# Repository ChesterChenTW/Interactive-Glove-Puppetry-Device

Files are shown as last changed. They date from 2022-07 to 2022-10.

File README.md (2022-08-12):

Wallpaper_Text

<p align="center">
    本專案將台灣布袋戲，結合互動裝置與開放資源
</p>
<p align="center">
    希望讓更多人能夠認識，並親自體驗傳統文化！ 
</p>  

## 開始著手
1. 下載[資源庫壓縮檔](https://github.com/ChesterChenTW/Interactive-Glove-Puppetry-Device/archive/refs/heads/main.zip)
1. 3D列印 "STL File" 資料夾內的檔案
1. 準備需要的材料，可見[物料清單](https://docs.google.com/spreadsheets/d/1u8G3vyJboXI-Y3cjxOG-QFLHkgTOIldBRjKiVYlQXxE/edit?usp=sharing)
1. 跟著[組裝指示](https://github.com/ChesterChenTW/Interactive-Glove-Puppetry-Device/wiki#%E7%B5%84%E8%A3%9D%E6%8C%87%E7%A4%BA)逐步完成裝置
1. 體驗以手把操控戲偶的樂趣！

## 授權條款
<br />本資源平台提供的內容均採用<a rel="license" href="https://creativecommons.org/licenses/by/4.0/deed.zh_TW">創用 CC 姓名標示 4.0 國際 授權條款</a>授權。  
允許重製、散布、傳輸以及修改著作（包括商業性利用），惟使用時須註明本平台的連結。

⚠️ 注意
1. 本平台僅作為內容提供，不對任何衍生或使用之損害負責，使用者須自行評估並注意安全
1. 修改原始檔案（例如韌體）可能影響裝置控制機制，建議需具備一定工程能力

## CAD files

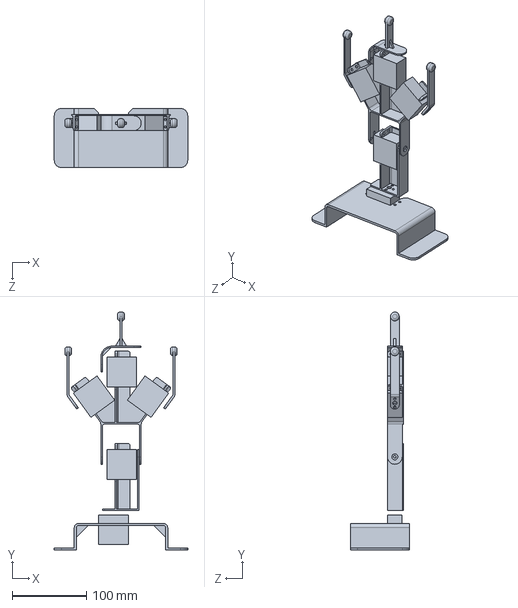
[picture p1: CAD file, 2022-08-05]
Original CAD File/Solidworks 2018/robotic.SLDPRT
180.0 x 320.7 x 80.0 mm

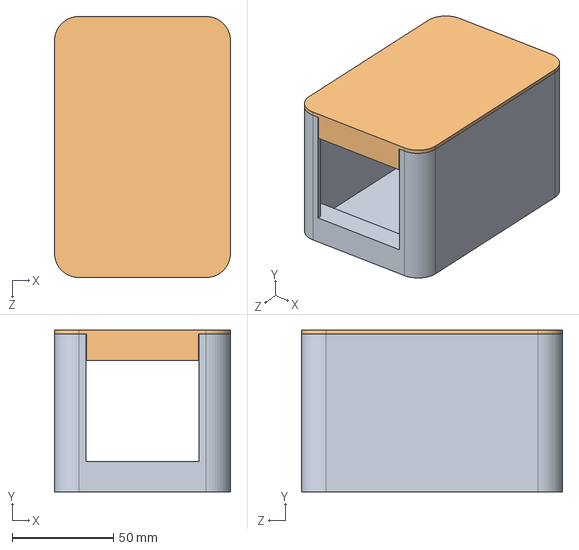
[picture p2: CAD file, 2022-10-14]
Original CAD File/STEP/robotic case.STEP
87.0 x 80.0 x 129.0 mm

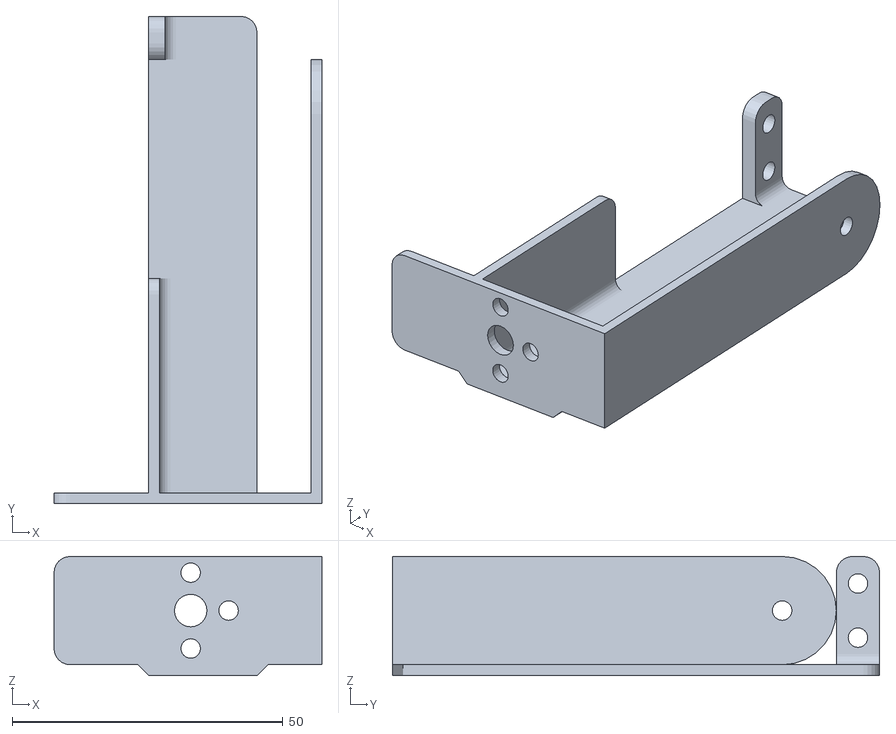
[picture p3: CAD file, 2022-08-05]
STL File/robotic_lower body.STL
49.5 x 90.0 x 22.0

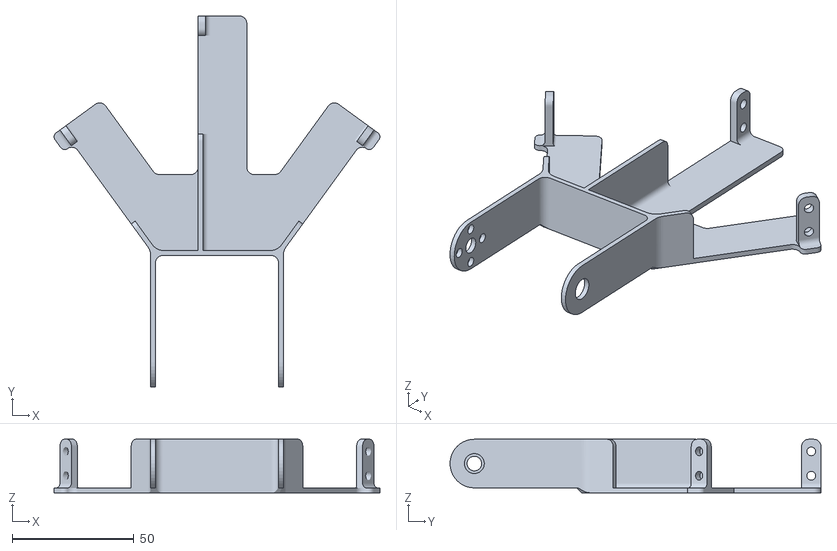
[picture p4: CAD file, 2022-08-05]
STL File/robotic_upper body.STL
133.9 x 152.4 x 22.0

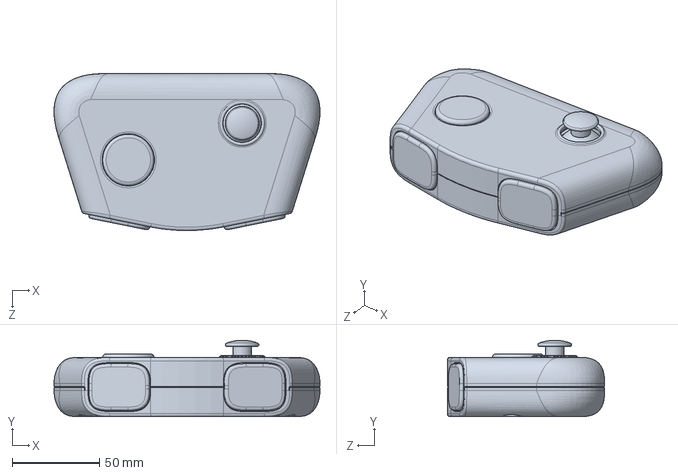
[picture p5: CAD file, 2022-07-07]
Original CAD File/Solidworks 2018/controller.SLDPRT
152.3 x 43.8 x 89.9 mm

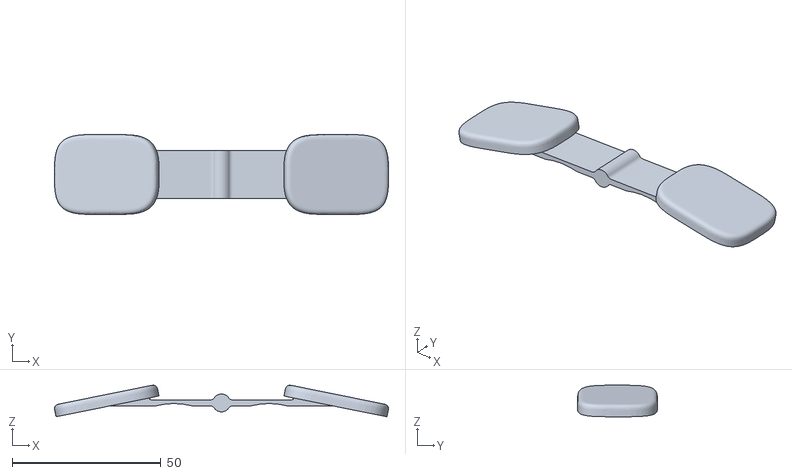
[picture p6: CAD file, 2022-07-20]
STL File/controller_shoulder button.STL
112.3 x 26.8 x 10.6

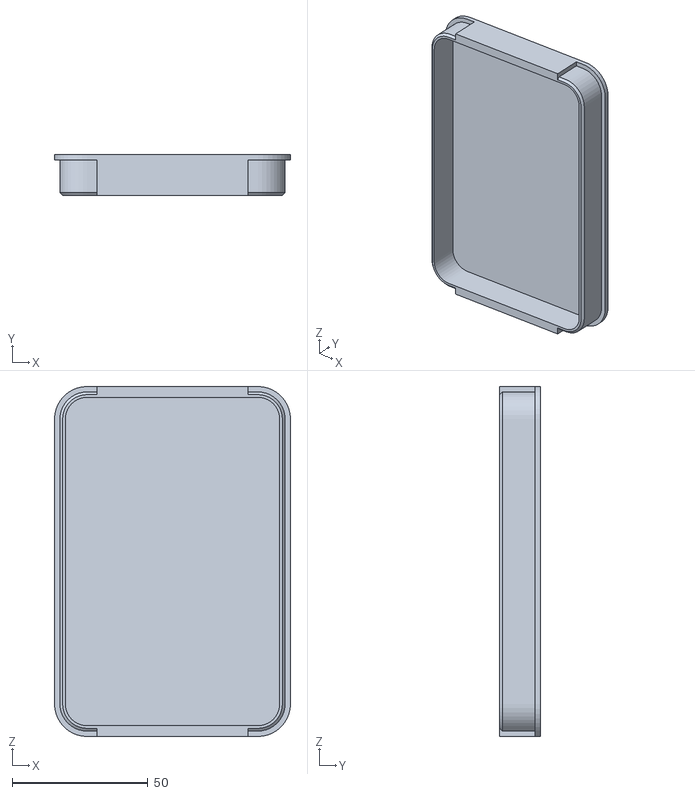
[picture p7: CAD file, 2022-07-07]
STL File/robotic case_cover.STL
87.0 x 15.0 x 129.0

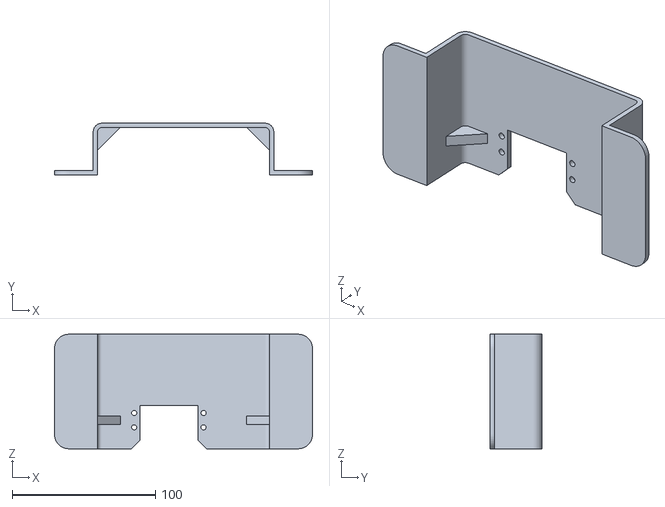
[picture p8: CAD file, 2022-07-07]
STL File/robotic_bottom.STL
180.0 x 36.0 x 80.0

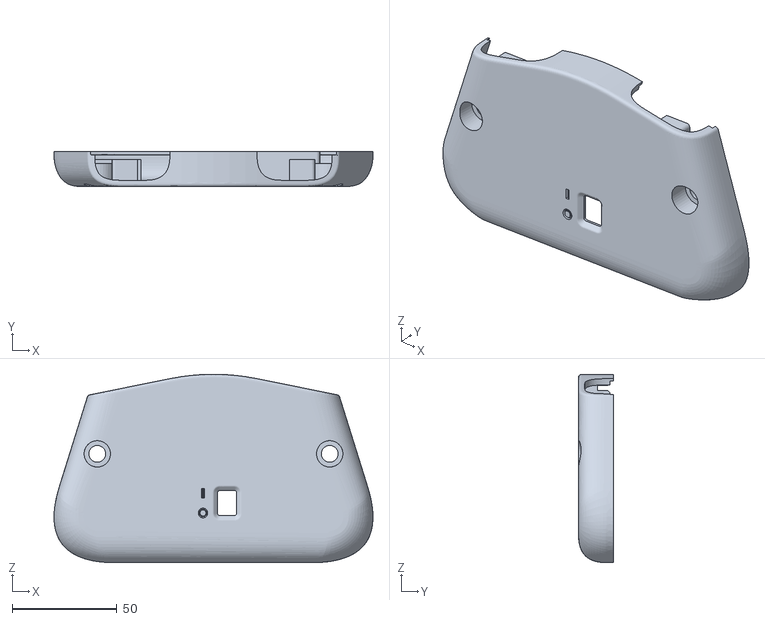
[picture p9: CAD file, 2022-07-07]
STL File/controller_bottom cover.STL
152.3 x 16.8 x 90.0

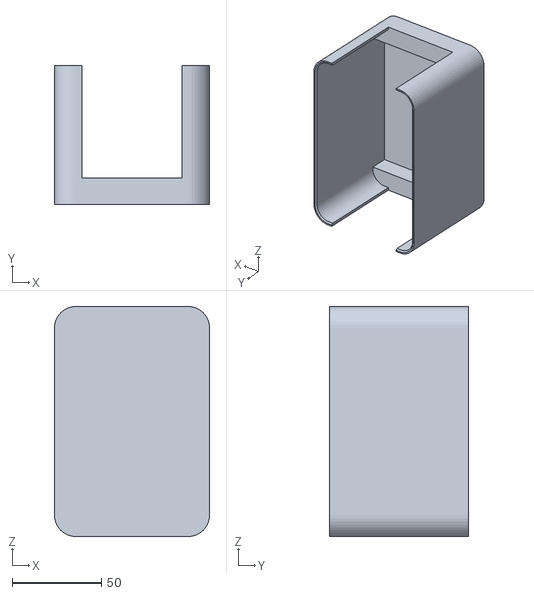
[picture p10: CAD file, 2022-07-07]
STL File/robotic case_case.STL
87.0 x 78.0 x 129.0

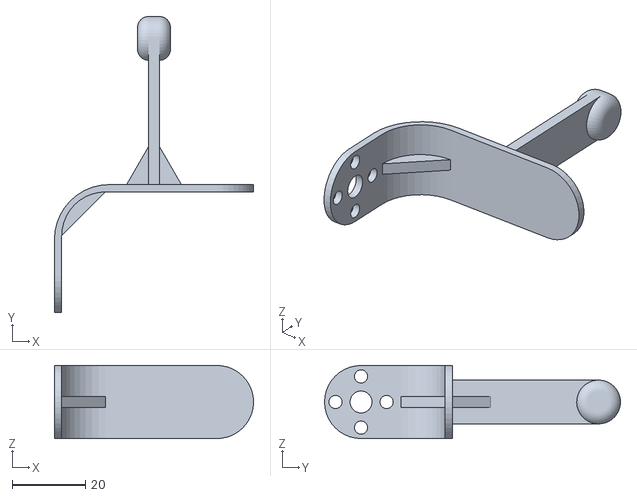
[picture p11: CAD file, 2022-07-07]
STL File/robotic_head.STL
54.5 x 81.0 x 20.0

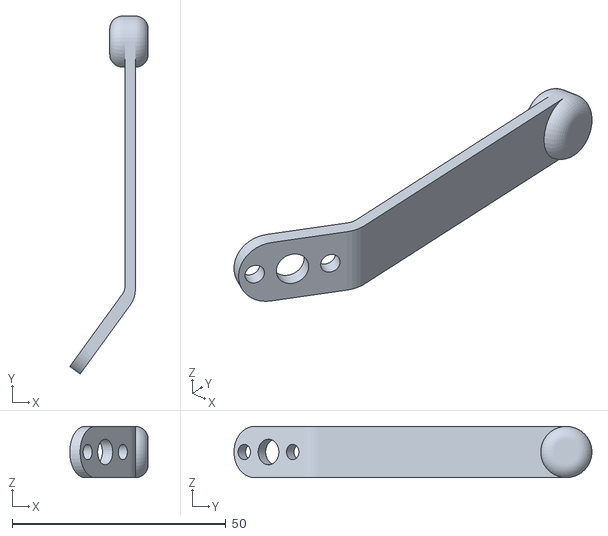
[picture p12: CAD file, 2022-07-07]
STL File/robotic_arm.STL
18.3 x 83.8 x 12.0

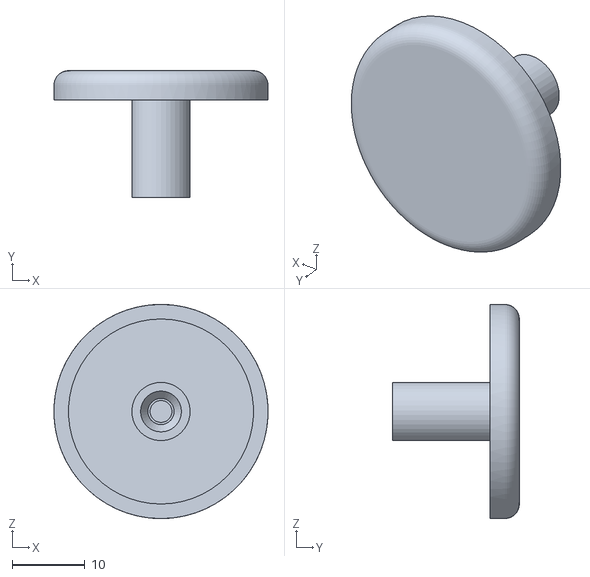
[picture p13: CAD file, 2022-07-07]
STL File/controller_top button.STL
29.4 x 17.4 x 29.4

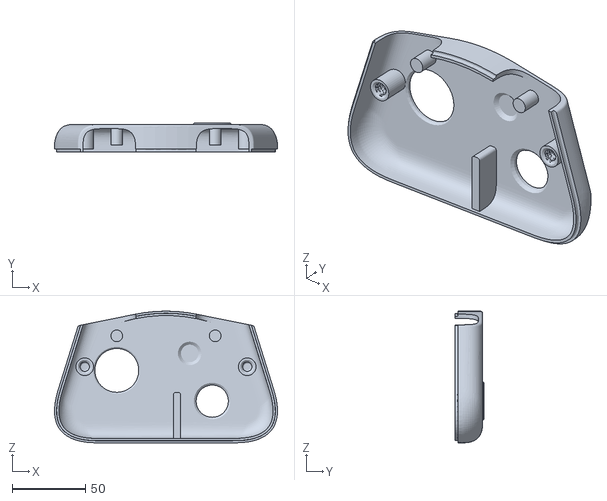
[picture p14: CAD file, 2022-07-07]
STL File/controller_top cover.STL
152.3 x 20.0 x 90.0

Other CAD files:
Original CAD File/STEP/robotic.STEP
Original CAD File/Solidworks 2018/robotic case.SLDPRT
Original CAD File/Solidworks 2018/controller_screw.SLDPRT
Original CAD File/STEP/controller_screw.STEP
STL File/controller_screw.STL

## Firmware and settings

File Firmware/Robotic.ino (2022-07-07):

#include <ArduinoBLE.h>
#include <Servo.h>

/*---BLE parameter---*/
const char* padService = "180F";
const char* TBtnValChar = "5442";
const char* RBtnValChar = "5242";
const char* LBtnValChar = "4c42";
const char* RadValChar = "5241";
const char* DegValChar = "4445";

/*---BLE parameter---*/
float oldTBtn = 0; float oldRBtn = 0; float oldLBtn = 0;
float oldRad = 0; float oldDeg = 0;

Servo servo1;  // 建立SERVO物件
Servo servo2;
Servo servo3;
Servo servo4;
Servo servo5;

int servoDeg1 = 90; // 馬達初始角度
int servoDeg2 = 90;
int servoDeg3 = 90;
int servoDeg4 = 45;
int servoDeg5 = 135;

const int FILTER_N = 10; //馬達濾波參數
int Filter1_Value; 
int Filter2_Value;
int Filter3_Value;
int Filter4_Value;
int Filter5_Value;


void setup() {
  Serial.begin(9600);

  int i;
  for (i = 0; i < FILTER_N; i++) {
    Filter1_Value = Filter1();
    Filter2_Value = Filter2();
    Filter3_Value = Filter3();
    Filter4_Value = Filter4();
    Filter5_Value = Filter5();
    delay(500);
  }

  servo1.attach(6);  // 設定要將伺服馬達接到哪一個PIN腳
  servo1.write(Filter1_Value);
  delay(500);
  servo2.attach(5);
  servo2.write(Filter2_Value);
  delay(500);
  servo3.attach(4);
  servo3.write(Filter3_Value);
  delay(500);
  servo4.attach(3);
  servo4.write(Filter4_Value);
  delay(500);
  servo5.attach(2);
  servo5.write(Filter5_Value);
  delay(500);

  BLE_init();
}

void loop() {
  connectToPeripheral();
}

void connectToPeripheral() {
  BLEDevice peripheral;

  Serial.println("- Discovering peripheral device...");

  do
  {
    BLE.scanForUuid(padService);
    peripheral = BLE.available();
  } while (!peripheral);

  if (peripheral) {
    Serial.println("* Peripheral device found!");
    Serial.print("* Device MAC address: ");
    Serial.println(peripheral.address());
    Serial.print("* Device name: ");
    Serial.println(peripheral.localName());
    Serial.print("* Advertised service UUID: ");
    Serial.println(peripheral.advertisedServiceUuid());
    Serial.println(" ");
    BLE.stopScan();
    controlPeripheral(peripheral);
  }
}

void controlPeripheral(BLEDevice peripheral) {
  Serial.println("- Connecting to peripheral device...");

  if (peripheral.connect()) {
    Serial.println("* Connected to peripheral device!");
    Serial.println(" ");
  } else {
    Serial.println("* Connection to peripheral device failed!");
    Serial.println(" ");
    return;
  }

  Serial.println("- Discovering peripheral device attributes...");
  if (peripheral.discoverAttributes()) {
    Serial.println("* Peripheral device attributes discovered!");
    Serial.println(" ");
  } else {
    Serial.println("* Peripheral device attributes discovery failed!");
    Serial.println(" ");
    peripheral.disconnect();
    return;
  }

  BLECharacteristic TBtnValChar = peripheral.characteristic("5442");
  BLECharacteristic RBtnValChar = peripheral.characteristic("5242");
  BLECharacteristic LBtnValChar = peripheral.characteristic("4c42");
  BLECharacteristic RadValChar = peripheral.characteristic("5241");
  BLECharacteristic DegValChar = peripheral.characteristic("4445");

  if (!TBtnValChar || !RBtnValChar || !LBtnValChar || !RadValChar || !DegValChar) {
    Serial.println("* Peripheral device does not have gesture_type characteristic!");
    peripheral.disconnect();
    return;
  } else if (!TBtnValChar.canSubscribe() || !RBtnValChar.canSubscribe() ||
             !LBtnValChar.canSubscribe() || !RadValChar.canSubscribe() || !DegValChar.canSubscribe()) {
    Serial.println("simple key characteristic is not subscribable!");
    peripheral.disconnect();
    return;
  } else if (!TBtnValChar.subscribe() || !RBtnValChar.subscribe() ||
             !LBtnValChar.subscribe() || !RadValChar.subscribe() || !DegValChar.subscribe()) {
    Serial.println("subscription failed!");
    peripheral.disconnect();
    return;
  }

  while (peripheral.connected()) {
    /*--readData--*/
    oldTBtn = getPadVal(TBtnValChar, oldTBtn, 1);
    oldRBtn = getPadVal(RBtnValChar, oldRBtn, 1);
    oldLBtn = getPadVal(LBtnValChar, oldLBtn, 1);
    oldRad = getPadVal(RadValChar, oldRad, 1);
    oldDeg = getPadVal(DegValChar, oldDeg, 1);
    /*--readData--*/

    Serial.print("Already get all data!");
    Serial.println("");

    if (oldRad == 0 || oldDeg == 0 ) { //----- servo1、2 控制
      servoDeg1 = 90;
      servoDeg2 = 90;
    }
    else if (oldRad > 0 && oldDeg >= 0 && oldDeg <= 180) {
      servoDeg1 = map(oldDeg, 0, 180, 45, 135);
      servoDeg2 = round(90 - oldRad * 30);
    }
    else if (oldDeg < 0 && oldDeg >= -90) {
      servoDeg1 = 45;
      servoDeg2 = round(90 - oldRad * 30);
    }
    else if (oldDeg < -90) {
      servoDeg1 = 135;
      servoDeg2 = round(90 - oldRad * 30);
    }
    Filter1_Value = Filter1();
    servo1.write(Filter1_Value);
    Filter2_Value = Filter2();
    servo2.write(Filter2_Value);

    if (oldTBtn == 1) { //----- servo3 控制
      if (servoDeg3 > 30) {
        servoDeg3 = servoDeg3 - 12;
      }
    }
    else if (oldTBtn == 0) {
      if (servoDeg3 < 90) {
        servoDeg3 = servoDeg3 + 12;
      }
    }
    Filter3_Value = Filter3();
    servo3.write(Filter3_Value);

    if (oldRBtn == 1) { //----- servo4 控制
      if (servoDeg4 < 135) {
        servoDeg4 = servoDeg4 + 18;
      }
    }
    else if (oldRBtn == 0) {
      if (servoDeg4 > 45) {
        servoDeg4 = servoDeg4 - 18;
      }
    }
    Filter4_Value = Filter4();
    servo4.write(Filter4_Value);

    if (oldLBtn == 1) { //----- servo5 控制
      if (servoDeg5 > 45) {
        servoDeg5 = servoDeg5 - 18;
      }
    }
    else if (oldLBtn == 0) {
      if (servoDeg5 < 135) {
        servoDeg5 = servoDeg5 + 18;
      }
    }
    Filter5_Value = Filter5();
    servo5.write(Filter5_Value);

  }
  Serial.println("- Peripheral device disconnected!");
}

void BLE_init() {
  if (!BLE.begin()) {
    Serial.println("* Starting Bluetooth® Low Energy module failed!");
    while (1);
  }

  BLE.setLocalName("Nano 33 BLE (Central)");
  BLE.advertise();
  Serial.println("Arduino Nano 33 BLE Sense (Central Device)");
  Serial.println(" ");
}

float getPadVal(BLECharacteristic c1, float oldF, int mod) {
  float f1 = oldF;
  Serial.print(f1);
  Serial.print(',');

  c1.read();
  if (c1.valueUpdated())
    f1 = getData(c1.value(), c1.valueLength(), mod);

  return f1;
}

union dat {
    unsigned char asdf[4];
    float zxcv;
    int qwer;
  };

float getData(const unsigned char data[], int length, int mod) {
  dat dat;
  for (int i = 0; i < length; i++) {
    dat.asdf[i] = data[i];
  }
  return mod == 1 ? dat.zxcv : dat.qwer;
}

int filter1_buf[FILTER_N + 1];
int Filter1() {
  int i;
  int filter1_sum = 0;
  filter1_buf[FILTER_N] = servoDeg1;
  for (i = 0; i < FILTER_N; i++) {
    filter1_buf[i] = filter1_buf[i + 1]; // 所有資料左移，低位仍掉
    filter1_sum += filter1_buf[i];
  }
  return (int)(filter1_sum / FILTER_N);
}

int filter2_buf[FILTER_N + 1];
int Filter2() {
  int i;
  int filter2_sum = 0;
  filter2_buf[FILTER_N] = servoDeg2;
  for (i = 0; i < FILTER_N; i++) {
    filter2_buf[i] = filter2_buf[i + 1]; // 所有資料左移，低位仍掉
    filter2_sum += filter2_buf[i];
  }
  return (int)(filter2_sum / FILTER_N);
}

int filter3_buf[FILTER_N + 1];
int Filter3() {
  int i;
  int filter3_sum = 0;
  filter3_buf[FILTER_N] = servoDeg3;
  for (i = 0; i < FILTER_N; i++) {
    filter3_buf[i] = filter3_buf[i + 1]; // 所有資料左移，低位仍掉
    filter3_sum += filter3_buf[i];
  }
  return (int)(filter3_sum / FILTER_N);
}

int filter4_buf[FILTER_N + 1];
int Filter4() {
  int i;
  int filter4_sum = 0;
  filter4_buf[FILTER_N] = servoDeg4;
  for (i = 0; i < FILTER_N; i++) {
    filter4_buf[i] = filter4_buf[i + 1]; // 所有資料左移，低位仍掉
    filter4_sum += filter4_buf[i];
  }
  return (int)(filter4_sum / FILTER_N);
}

int filter5_buf[FILTER_N + 1];
int Filter5() {
  int i;
  int filter5_sum = 0;
  filter5_buf[FILTER_N] = servoDeg5;
  for (i = 0; i < FILTER_N; i++) {
    filter5_buf[i] = filter5_buf[i + 1]; // 所有資料左移，低位仍掉
    filter5_sum += filter5_buf[i];
  }
  return (int)(filter5_sum / FILTER_N);
}

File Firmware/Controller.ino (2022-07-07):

#include <ArduinoBLE.h>
#include <math.h>

int TopButton_P = 4;  //Pull-up resistor for TopButton
int TopButton_G = 5; //Ground for TopButton
int RightButton_P = 6;
int RightButton_G = 7;
int LeftButton_P = 9;
int LeftButton_G = 11;
int JoyStick_V = 19; //Vin for joystick
int JoyStick_G = 18; //Gnd for joystick
int JoyStick_X = 3; //Vx for joystick
int JoyStick_Y = 2; //Vy for joystick

/*---BLE parameter---*/
/*-- BLE33 BatteryMonitor Example --*/
// Bluetooth® Low Energy Battery Service
BLEService padService("180F");

// Bluetooth® Low Energy Battery Level Characteristic
BLEFloatCharacteristic TBtnValChar("5442",  //TBtn  // standard 16-bit characteristic UUID
                                   BLERead | BLENotify); // remote clients will be able to get notifications if this characteristic changes
BLEFloatCharacteristic RBtnValChar("5242", BLERead | BLENotify);  //RBtn
BLEFloatCharacteristic LBtnValChar("4c42", BLERead | BLENotify);  //LBtn
BLEFloatCharacteristic  RadValChar("5241", BLERead | BLENotify);  //RAD
BLEFloatCharacteristic  DegValChar("4445", BLERead | BLENotify);  //DEG

float oldTBtn = 0; float oldRBtn = 0; float oldLBtn = 0;
float oldRad = 0; float oldDeg = 0;

long previousMillis = 0;  // last time the battery level was checked, in ms
const long intervalMillis = 50;
/*---BLE parameter---*/

void setup() {
  Serial.begin(9600);
  pinMode(TopButton_P, INPUT_PULLUP);
  pinMode(RightButton_P, INPUT_PULLUP);
  pinMode(LeftButton_P, INPUT_PULLUP);

  pinMode(TopButton_G, OUTPUT);
  pinMode(RightButton_G, OUTPUT);
  pinMode(LeftButton_G, OUTPUT);
  pinMode(JoyStick_V, OUTPUT);
  pinMode(JoyStick_G, OUTPUT);

  digitalWrite(TopButton_G, LOW);
  digitalWrite(RightButton_G, LOW);
  digitalWrite(LeftButton_G, LOW);
  digitalWrite(JoyStick_V, HIGH);
  digitalWrite(JoyStick_G, LOW);

  pinMode(LEDR, OUTPUT);
  pinMode(LEDG, OUTPUT);
  pinMode(LEDB, OUTPUT);

  digitalWrite(LEDR, LOW);
  digitalWrite(LEDG, LOW);
  digitalWrite(LEDB, LOW);

  BLE_init(); //initialize BLE as peripheral
}

void loop() {
  connectedByCentral();
}

void BLE_init() {
  // begin initialization
  if (!BLE.begin()) {
    Serial.println("starting BLE failed!");

    while (1);
  }

  BLE.setLocalName("PadController");
  BLE.setAdvertisedService(padService); // add the service UUID
  padService.addCharacteristic(TBtnValChar); // add the characteristic
  padService.addCharacteristic(RBtnValChar);
  padService.addCharacteristic(LBtnValChar);
  padService.addCharacteristic(RadValChar);
  padService.addCharacteristic(DegValChar);
  BLE.addService(padService); // Add the battery service
  float initInt = 0;
  TBtnValChar.writeValue(initInt); // set initial value for this characteristic
  RBtnValChar.writeValue(initInt);
  LBtnValChar.writeValue(initInt);
  RadValChar.writeValue(initInt);
  DegValChar.writeValue(initInt);

  // start advertising
  BLE.advertise();

  Serial.println("Bluetooth® device active, waiting for connections...");
}

void connectedByCentral() {
  // wait for a Bluetooth® Low Energy central
  BLEDevice central = BLE.central();

  // if a central is connected to the peripheral:
  if (central) {
    /*---connect to central---*/
    Serial.print("Connected to central: ");
    Serial.println(central.address());
    /*-- turn on the LED to indicate the connection: --*/
    digitalWrite(LED_BUILTIN, HIGH);

    /*---central connecting & streaming data---*/
    // while the central is connected:
    // check the val every intervalMillis
    while (central.connected()) {
      long currentMillis = millis();
      // if intervalMillis have passed, check the val:
      if (currentMillis - previousMillis >= intervalMillis) {
        previousMillis = currentMillis;
        updatePadVal(); // read new val & send to central
      }
    }

    /*---central disconnect---*/
    digitalWrite(LED_BUILTIN, LOW);
    Serial.print("Disconnected from central: ");
    Serial.println(central.address());
  }
}

int counter = 2;
void updatePadVal() {
  if (counter % 2 == 0 ) {
    oldTBtn = updateBtnState(TopButton_P); //偵測TBtn是否按
    TBtnValChar.writeValue(oldTBtn);
    oldRBtn = updateBtnState(RightButton_P); //偵測RBtn是否按下
    RBtnValChar.writeValue(oldRBtn);
    oldLBtn = updateBtnState(LeftButton_P); //偵測LBtn是否按下
    LBtnValChar.writeValue(oldLBtn);
    //TBtnValChar.writeValue((oldTBtn * 1) + (oldRBtn * 2) + (oldLBtn * 4));
  } else if (counter % 3 == 0 ) {
    updateJoystickVal();
  }

  counter = (counter % 3 == 0) ? 1 : counter ;
  counter++;
}

float updateBtnState(int iBtn) {
  float btnData = 0;
  btnData = (digitalRead(iBtn) == LOW) ? 1.0 : 0.0;
  return btnData;
}

void updateJoystickVal() {
  long JS_VX = analogRead(JoyStick_X) - 512;
  long JS_VY = 512 - analogRead(JoyStick_Y);
  float RAD = sqrt(JS_VX * JS_VX + JS_VY * JS_VY) / 500; //轉換成極座標且半徑等於1
  int DEG = atan2 (JS_VY, JS_VX) * 57.296; //轉換成極座標角度

  if (RAD >= 0.25 && RAD <= 1) {
    RadValChar.writeValue(RAD);
    DegValChar.writeValue(DEG);
    oldRad = RAD; oldDeg = DEG;
  }
  else if (RAD > 1) {
    RadValChar.writeValue(1.0);
    DegValChar.writeValue(DEG);
  }
  else {
    RadValChar.writeValue(0.0);
    DegValChar.writeValue(0.0);
  }
}

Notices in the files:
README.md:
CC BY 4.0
